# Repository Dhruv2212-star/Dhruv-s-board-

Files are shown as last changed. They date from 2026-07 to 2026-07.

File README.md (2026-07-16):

The Devboard is divided into the following blocks:  
1. **Block 1 — USB Power Input & Protection**  
2. **Block 2 — 3.3 V Power Supply**  
3. **Block 3 — STM32 Minimum System**  
4. **Block 4 — SWD Programming Interface**  
5. **Block 5 — User Interface**  
6. **Block 6 — GPIO Expansion**  
   ## lets understand why each component was placed and what is it's function block wise
Block 1 — USB Power Input & Protection: Provide safe 5 V input from a USB-C connector and protect the board against faults before supplying the voltage regulator

   | Ref | Component                 | Why it was used                                               | Function                                                      |
| --- | ------------------------- | ------------------------------------------------------------- | ------------------------------------------------------------- |
| J1  | USB-C Receptacle (16-pin) | Standard USB connector for power and future USB communication | Accepts 5 V power from a USB cable                            |
| F1  | MF-R110 Resettable Fuse   | Prevents excessive current from damaging the board            | Disconnects power during overcurrent and automatically resets |
| D1  | ESD9B5.0ST5G TVS Diode    | USB connectors are exposed to electrostatic discharge         | Protects the power input from ESD and voltage spikes          |
| C1  | 10 µF Capacitor           | Bulk input capacitor                                          | Smooths incoming 5 V supply and handles sudden current demand |
| C2  | 100 nF Capacitor          | High-frequency bypass capacitor                               | Filters high-frequency noise on the USB supply                |  

Block 2 — 3.3 V Power Supply: Convert USB 5 V into a stable 3.3 V supply for the STM32 and peripherals  
   
   | Ref | Component        | Why it was used                                                    | Function                                                      |
| --- | ---------------- | ------------------------------------------------------------------ | ------------------------------------------------------------- |
| U1  | AP2112K-3.3 LDO  | Low-noise regulator capable of supplying the STM32 and peripherals | Converts 5 V to regulated 3.3 V                               |
| C3  | 10 µF Capacitor  | Output stability                                                   | Prevents regulator oscillation and supplies transient current |
| C4  | 100 nF Capacitor | High-frequency filtering                                           | Removes switching noise from the regulator output             |

3. Block 3 — STM32 Minimum System: Provide all circuitry required for reliable STM32 operation.  
   
| Ref | Component | Why it was used | Function |
| --- | --- | --- | --- |
| U2  | STM32F103C8Tx | Main microcontroller | Executes firmware and controls all peripherals |
| C5  | 100 nF | Local decoupling | Filters VDD (Pin 24) |
| C6  | 100 nF | Local decoupling | Filters VDD (Pin 36) |
| C7  | 100 nF | Local decoupling | Filters VDD (Pin 48) |
| C8  | 100 nF | Analog supply bypass | Stabilizes VDDA for ADC and analog peripherals |
| Y1  | 8 MHz Crystal | Accurate external clock | Provides precise system clock reference |
| C9  | 22 pF | Crystal load capacitor  | Ensures stable crystal oscillation |
| C10 | 22 pF | Crystal load capacitor  | Ensures stable crystal oscillation |
| R4  | 10 kΩ | NRST pull-up | Keeps MCU out of reset during normal operation |
| SW2 | Push Button | Manual reset | Pulls NRST low to reset the MCU |
| R5  | 10 kΩ | BOOT0 pull-down | Keeps BOOT0 low for normal Flash boot |
| SW1 | Push Button | Bootloader entry | Pulls BOOT0 high when pressed during reset |

4. Block 4 — SWD Programming Interface: Allow firmware upload and debugging using an ST-Link programmer  
   
 **Power LED**
| Ref | Component | Why it was used | Function |
| --- | --- | --- | --- |
| J2  | 2×5 SWD Header | Standard ARM Cortex programming interface | Connects ST-Link debugger to the MCU |

5. Block 5 — User Interface: Provide simple visual status indication
   
| Ref | Component | Why it was used | Function |
| --- | --- | --- | --- |
| D2  | Green LED | Indicates board is powered | Lights whenever 3.3 V is present |
| R1  | 1 kΩ | LED current limiting | Protects LED and regulator |

**User LED**
| Ref | Component | Why it was used | Function |
| --- | --- | --- | --- |
| D3  | User LED  | Software-controlled indicator | Used for testing and debugging |
| R6  | 330 Ω | LED current limiting | Limits current through the LED |  

**UART header**
| Ref | Component | Why it was used | Function |
| --- | --- | --- | --- |
| D3  | User LED  | Software-controlled indicator | Used for testing and debugging |
| R6  | 330 Ω | LED current limiting | Limits current through the LED |

6. Block 6 — GPIO Expansion: Expose nearly every GPIO pin of the STM32 for external circuits  
   
**Left header**
   | Ref | Component          | Function                                                          |
| --- | ------------------ | ----------------------------------------------------------------- |
| J4  | 1×20 Female Header | Provides access to GPIOs including NRST, BOOT0, PA0–PA7, PB0–PB15 |

**right header**
| Ref | Component | Function |
| --- | --- | --- |
| J5  | 1×20 Female Header | Provides access to GPIOs including PC13–PC15, PA8–PA15, PB3–PB9, SWD signals, power rails |

# Overall system architecture 
USB-C Input  
     │  
     Resettable Fuse  
     │  
     TVS Protection  
     │  
     Input Capacitors  
     │  
     AP2112K 3.3V Regulator  
     │  
     STM32F103C8T6  
     ├────────────── SWD Header  
     ├────────────── UART Header    
     ├────────────── Power LED  
     ├────────────── Crystal Oscillator  
     ├────────────── Reset Circuit  
     ├────────────── Boot Circuit  
     └────────────── GPIO Headers

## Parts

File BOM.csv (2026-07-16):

Reference | Value | Footprint
J1 | USB_C_Receptacle_USB2.0_16P | Connector_USB:USB_C_Receptacle_HCTL_HC-TYPE-C-16P-01A
F1 | Bourns MF-R110 | Fuse:Fuse_1206_3216Metric
D1 | ESD9B5.0ST5G | Diode_SMD:D_SOD-923
C1 | 10uF X7R 16V | Capacitor_SMD:C_0805_2012Metric
C2 | 100nF X7R | Capacitor_SMD:C_0805_2012Metric
U1 | AP2112K-3.3 | Package_TO_SOT_SMD:SOT-23-5
C3 | 10uF X7R 10V | Capacitor_SMD:C_0805_2012Metric
C4 | 100nF X7R | Capacitor_SMD:C_0805_2012Metric
U2 | STM32F103C8Tx | Package_QFP:LQFP-48_7x7mm_P0.5mm
C5 | 100nF X7R | Capacitor_SMD:C_0805_2012Metric
C6 | 100nF X7R | Capacitor_SMD:C_0805_2012Metric
C7 | 100nF X7R | Capacitor_SMD:C_0805_2012Metric
C8 | 100nF X7R | Capacitor_SMD:C_0805_2012Metric
Y1 | 8MHz Crystal | Crystal:Crystal_SMD_3225-4Pin_3.2x2.5mm
C9 | 22pF | Capacitor_SMD:C_0805_2012Metric
C10 | 22pF | Capacitor_SMD:C_0805_2012Metric
R4 | 10k | Resistor_SMD:R_0805_2012Metric
SW2 | SW_Push | Button_Switch_SMD:SW_SPST_SKQG_WithoutStem
R5 | 10k | Resistor_SMD:R_0805_2012Metric
SW1 | SW_Push | Button_Switch_SMD:SW_SPST_SKQG_WithoutStem
J2 | Conn_02x05_Odd_Even | Connector_PinHeader_2.54mm:PinHeader_2x05_P2.54mm_Vertical
D2 | Power LED | LED_SMD:LED_0805_2012Metric
R1 | 1k | Resistor_SMD:R_0805_2012Metric
D3 | User LED | LED_SMD:LED_0805_2012Metric
R6 | 330R | Resistor_SMD:R_0805_2012Metric
J3 | Conn_01x04 | Connector_PinHeader_2.54mm:PinHeader_1x04_P2.54mm_Vertical
J4 | Conn_01x20 | Connector_PinHeader_2.54mm:PinHeader_1x20_P2.54mm_Vertical
J5 | Conn_01x20 | Connector_PinHeader_2.54mm:PinHeader_1x20_P2.54mm_Vertical

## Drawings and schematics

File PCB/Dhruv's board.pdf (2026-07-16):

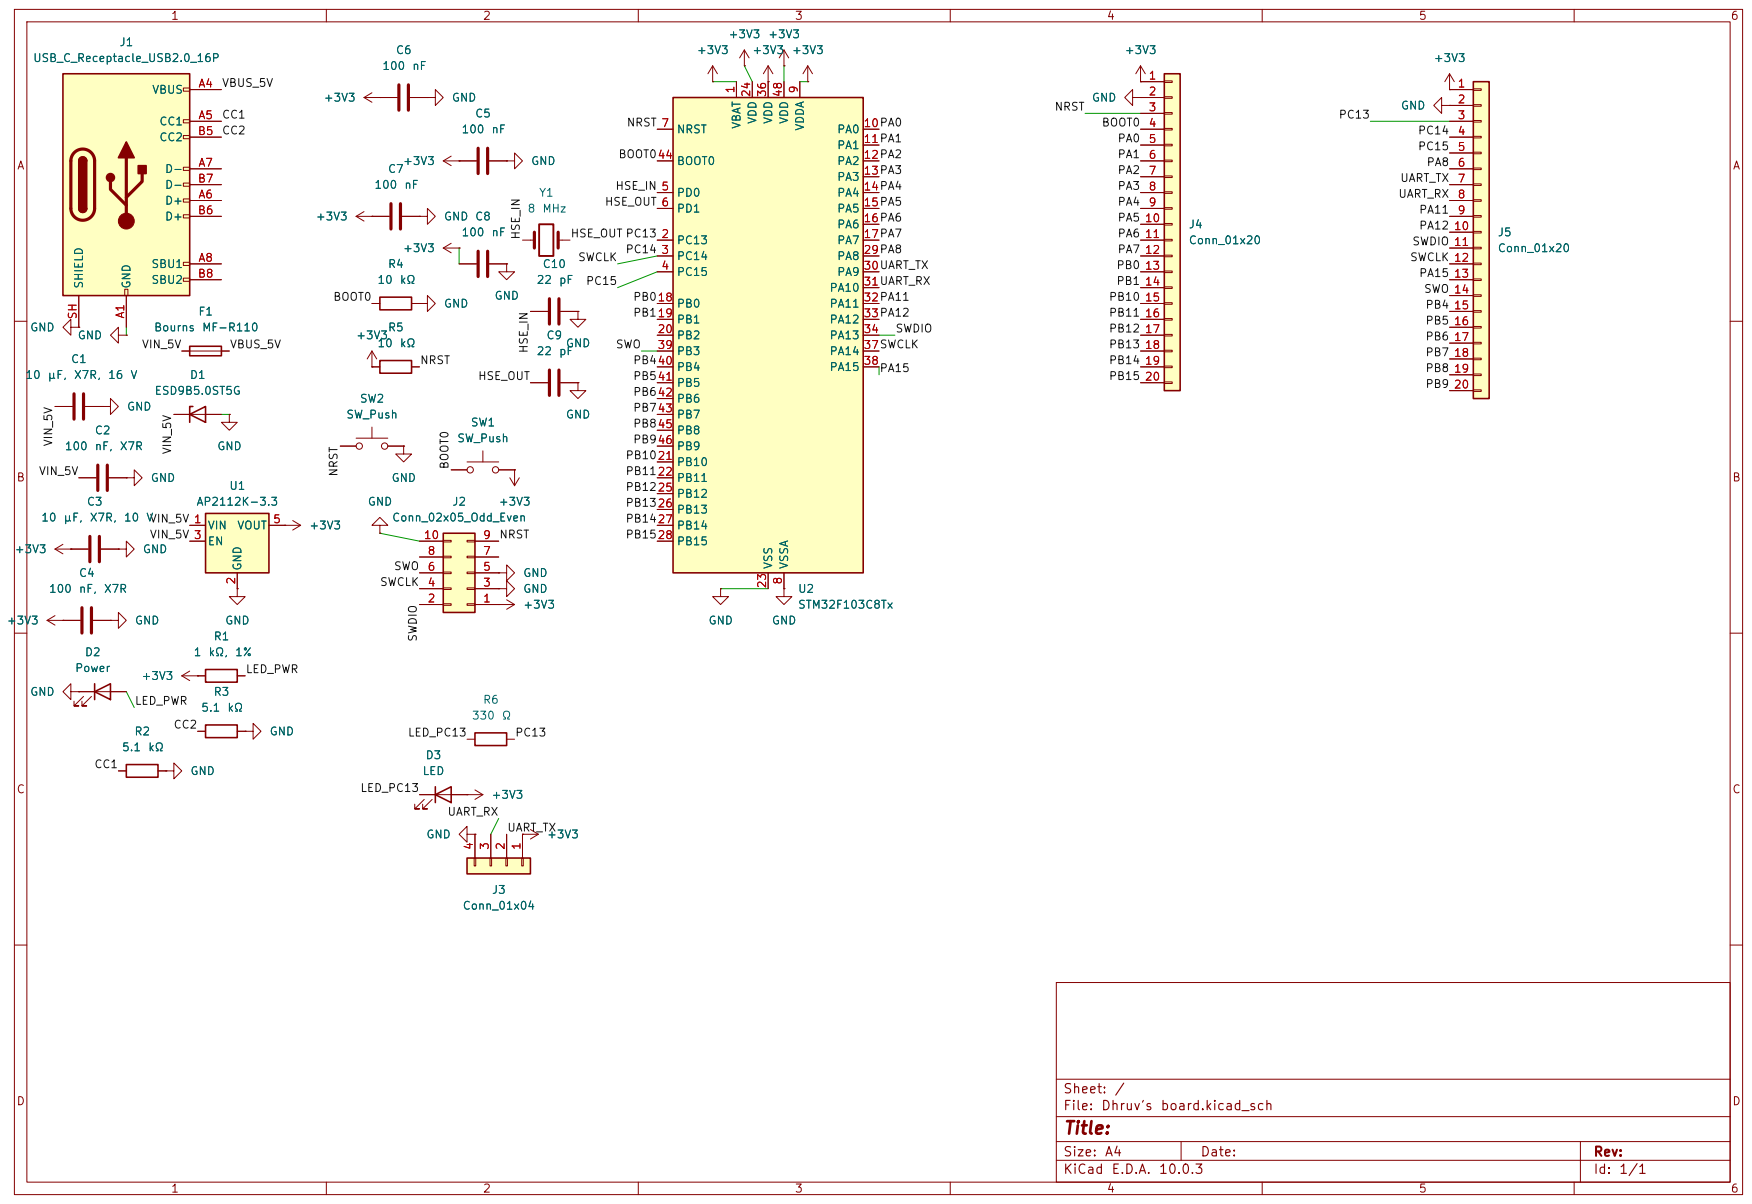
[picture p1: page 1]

Size: A4 | Rev:
KiCad E.D.A. 10.0.3 | Id: 1/1

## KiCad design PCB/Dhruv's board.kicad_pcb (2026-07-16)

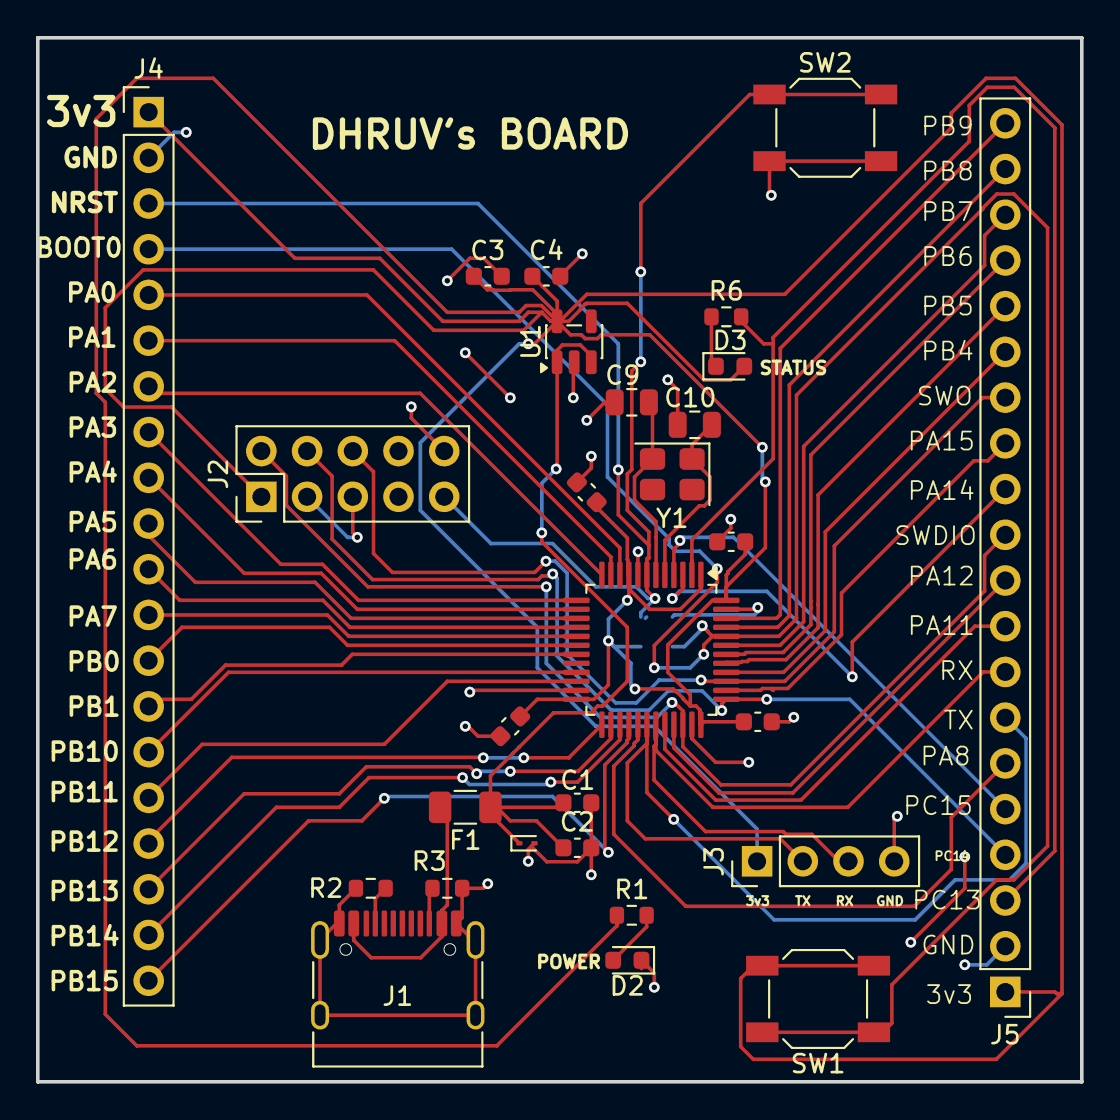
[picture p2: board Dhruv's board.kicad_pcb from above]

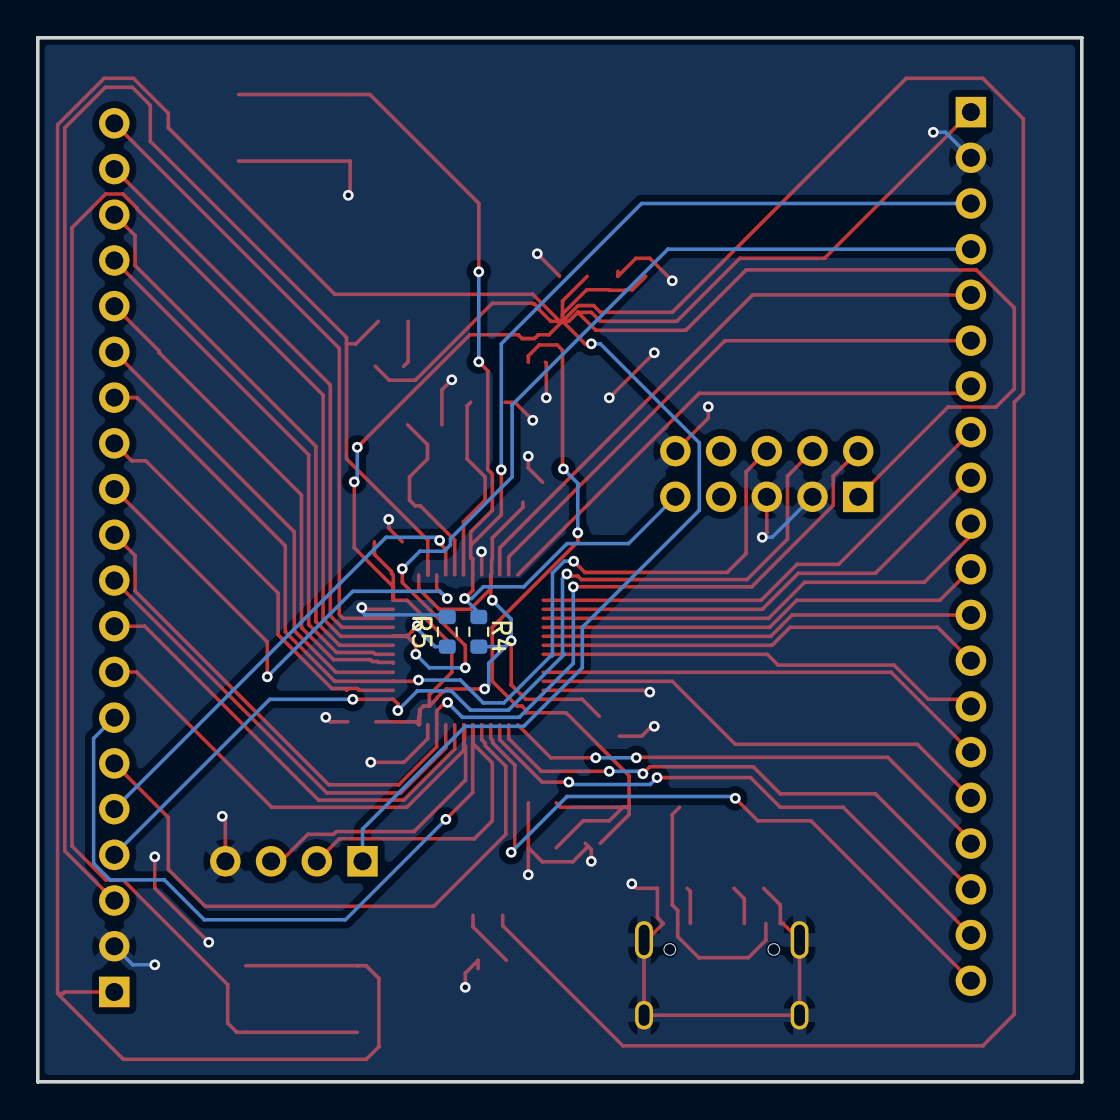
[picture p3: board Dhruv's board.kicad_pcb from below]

Board: 2 copper layers, 58.0 x 58.0 mm, 30 parts (2 on the bottom side), 45 nets.

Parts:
C1: 10 µF, X7R, 16 V; C_0603_1608Metric
C2, C4: 100 nF, X7R; C_0603_1608Metric
C3: 10 µF, X7R, 10 V; C_0603_1608Metric
C5, C6, C7, C8: 100 nF; C_0603_1608Metric
C9, C10: 22 pF; C_0805_2012Metric
D1: ESD9B5.0ST5G; D_SOD-923
D2: Power; LED_0603_1608Metric
D3: LED; LED_0603_1608Metric
F1: Bourns MF-R110; Fuse_1206_3216Metric
J1: USB_C_Receptacle_USB2.0_16P; USB_C_Receptacle_HRO_TYPE-C-31-M-12
J2: Conn_02x05_Odd_Even; PinHeader_2x05_P2.54mm_Vertical
J3: Conn_01x04; PinHeader_1x04_P2.54mm_Vertical
J4, J5: Conn_01x20; PinHeader_1x20_P2.54mm_Vertical
R1: 1 kΩ, 1%; R_0603_1608Metric
R2, R3: 5.1 kΩ; R_0603_1608Metric
R4, R5: 10 kΩ; R_0603_1608Metric
R6: 330 Ω; R_0603_1608Metric
SW1, SW2: SW_Push; SW_SPST_SKQG_WithoutStem
U1: AP2112K-3.3; SOT-23-5
U2: STM32F103C8Tx; LQFP-48_7x7mm_P0.5mm
Y1: 8 MHz; Crystal_SMD_3225-4Pin_3.2x2.5mm

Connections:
+3V3: C3.1, C4.1, C5.1, C6.1, C7.1, C8.1, D3.2 (A), J2.1, J3.1, J4.1, J5.1, R1.1, R4.1, SW1.2, U1.5 (VOUT), U2.1 (VBAT), U2.9 (VDDA), U2.24 (VDD), U2.36 (VDD), U2.48 (VDD)
/BOOT0: J4.4, R5.1, SW1.1, U2.44 (BOOT0)
/CC1: J1.A5 (CC1), R2.1
/CC2: J1.B5 (CC2), R3.1
/HSE_IN: C10.1, U2.5 (PD0), Y1.1
/HSE_OUT: C9.1, U2.6 (PD1), Y1.2
/LED_PC13: D3.1 (K), R6.1
/LED_PWR: D2.2 (A), R1.2
/NRST: J2.9, J4.3, R4.2, SW2.1, U2.7 (NRST)
/PA0: J4.5, U2.10 (PA0)
/PA1: J4.6, U2.11 (PA1)
/PA2: J4.7, U2.12 (PA2)
/PA3: J4.8, U2.13 (PA3)
/PA4: J4.9, U2.14 (PA4)
/PA5: J4.10, U2.15 (PA5)
/PA6: J4.11, U2.16 (PA6)
/PA7: J4.12, U2.17 (PA7)
/PA8: J5.6, U2.29 (PA8)
/PA11: J5.9, U2.32 (PA11)
/PA12: J5.10, U2.33 (PA12)
/PA15: J5.13, U2.38 (PA15)
/PB0: J4.13, U2.18 (PB0)
/PB1: J4.14, U2.19 (PB1)
/PB4: J5.15, U2.40 (PB4)
/PB5: J5.16, U2.41 (PB5)
/PB6: J5.17, U2.42 (PB6)
/PB7: J5.18, U2.43 (PB7)
/PB8: J5.19, U2.45 (PB8)
/PB9: J5.20, U2.46 (PB9)
/PB10: J4.15, U2.21 (PB10)
/PB11: J4.16, U2.22 (PB11)
/PB12: J4.17, U2.25 (PB12)
/PB13: J4.18, U2.26 (PB13)
/PB14: J4.19, U2.27 (PB14)
/PB15: J4.20, U2.28 (PB15)
/PC13: J5.3, R6.2, U2.2 (PC13)
/PC14: J2.4, J5.4, J5.12, U2.3 (PC14), U2.37 (PA14)
/PC15: J5.5, U2.4 (PC15)
/SWDIO: J2.2, J5.11, U2.34 (PA13)
/SWO: J2.6, J5.14, U2.39 (PB3)
/UART_RX: J3.3, J5.8, U2.31 (PA10)
/UART_TX: J3.2, J5.7, U2.30 (PA9)
/VBUS_5V: F1.2, J1.A4 (VBUS), J1.A9 (VBUS), J1.B4 (VBUS), J1.B9 (VBUS)
/VIN_5V: C1.1, C2.1, D1.1 (K), F1.1, U1.1 (VIN), U1.3 (EN)
GND: C1.2, C2.2, C3.2, C4.2, C5.2, C6.2, C7.2, C8.2, C9.2, C10.2, D1.2 (A), D2.1 (K), J1.A1 (GND), J1.A12 (GND), J1.B1 (GND), J1.B12 (GND), J1.SH (SHIELD), J2.3, J2.5, J2.10, J3.4, J4.2, J5.2, R2.2, R3.2, R5.2, SW2.2, U1.2 (GND), U2.8 (VSSA), U2.23 (VSS), U2.35 (VSS), U2.47 (VSS)

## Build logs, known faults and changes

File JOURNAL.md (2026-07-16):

# Schematic | Time taken- 2 hours and 6 mins  
Lapse- https://lapse.hackclub.com/timelapse/6EKB5NhbEQ2t  
1. POWER SYSTEM | 40 mins  

2.Block 2A – STM32 Core Power Connections | 10 mins  
 
3. BLOCK 2D- Clock circuit | 10 mins 

4.  Block 2E – SWD Programming Header | 10 mins  

5. Block 3: User I/O Connections | 20 mins  

6. Block 4: GPIO Expansion Headers  | 30 mins
   
7. Added footprints | 6 mins  

# PCB tracing | 4 hours 15 mins   
1. PCB tracing     
   Lapse-  https://lapse.hackclub.com/timelapse/bnAnlEk-080g  
   
2. Graphics for PCB  
   Lapse- https://lapse.hackclub.com/timelapse/UaSDh8AJdWyV  
   16 07 2026_12 23 58_REC

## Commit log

2026-07-15 power section
2026-07-15 completed schematic
2026-07-16 PCB tracing and graphics
2026-07-16 Project description
    added the instructions on why each component was used and what function does it complete in the circuit
2026-07-16 PCB schematic and tracings and Gerber files added
    [Dhruv's board.kicad_pcb, Dhruv's board.kicad_sch]
2026-07-16 added BOM
    [BOM.csv]
